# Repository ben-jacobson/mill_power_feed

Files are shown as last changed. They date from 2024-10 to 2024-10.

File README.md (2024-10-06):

# mill_power_feed
Motor control code for milling machine power feed unit. Uses Platform IO with the Arduino library

Requirements:
- Use Platform IO under visual studio code
- If PIO doesn't pick this up from the .ini file, set this up as an Arudino project with the ATMega328P as the target
- If PIO doesn't pick this up from the .ini file, install the library - AccelStepper
- Compile and build in Platform IO

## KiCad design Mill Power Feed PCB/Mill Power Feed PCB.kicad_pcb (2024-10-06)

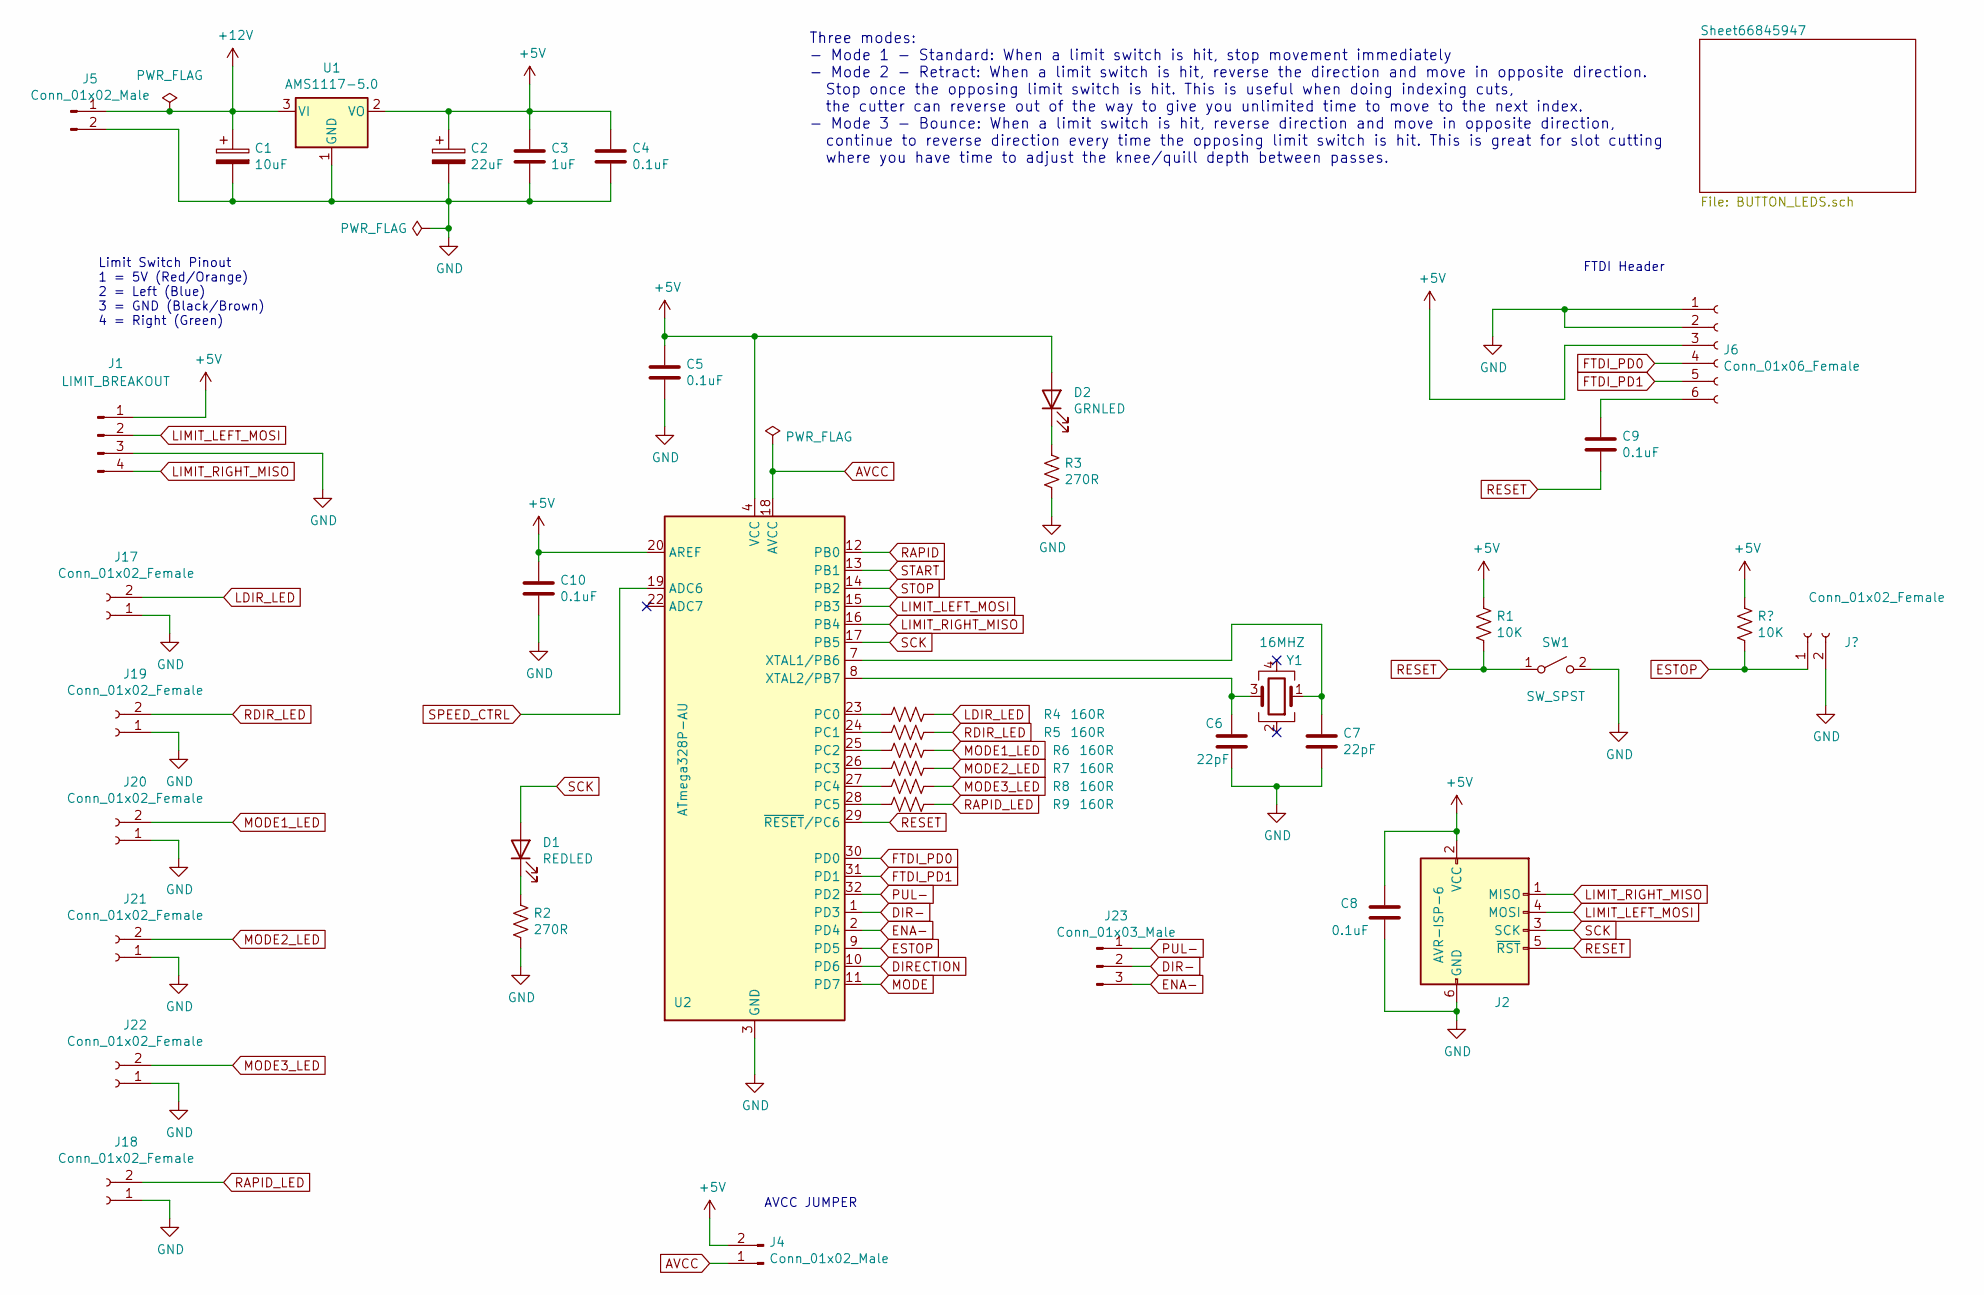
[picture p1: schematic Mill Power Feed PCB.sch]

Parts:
C1: 10uF; C_Elec_4x5.4; LCSC C134721
C2: 22uF; CP_EIA-3528-21_Kemet-B; LCSC C8020
C3: 1uF; C_0603_1608Metric; LCSC C28323
C4, C5, C8, C9, C10: 0.1uF; C_0603_1608Metric; LCSC C14663
C6, C7: 22pF; C_0603_1608Metric; LCSC C388039
D1: REDLED; LED_0603_1608Metric; LCSC C2286
D2: GRNLED; LED_0603_1608Metric; LCSC C72043
J1: LIMIT_BREAKOUT; JST_XH_B4B-XH-AM_1x04_P2.50mm_Vertical
J2: AVR-ISP-6; PinHeader_2x03_P2.54mm_Vertical
J4: Conn_01x02_Male; PinHeader_1x02_P2.54mm_Vertical
J5: Conn_01x02_Male; PinHeader_1x02_P2.54mm_Horizontal
J6: Conn_01x06_Female; PinSocket_1x06_P2.54mm_Vertical
J17, J18, J19, J20, J21, J22: Conn_01x02_Female; JST_XH_B2B-XH-AM_1x02_P2.50mm_Vertical
J23: Conn_01x03_Male; JST_XH_B3B-XH-AM_1x03_P2.50mm_Vertical
R1: 10K; R_0603_1608Metric; LCSC C25804
R2, R3: 270R; R_0603_1608Metric; LCSC C22966
R4, R5, R6, R7, R8, R9: 160R; R_0603_1608Metric
SW1: SW_SPST; SW_Push_1P1T_NO_6x6mm_H9.5mm; LCSC C620316
U1: AMS1117-5.0; SOT-223-3_TabPin2; LCSC C6187
U2: ATmega328P-AU; TQFP-32_7x7mm_P0.8mm; LCSC C14877
Y1: 16MHZ; Crystal_SMD_3225-4Pin_3.2x2.5mm; LCSC C13738

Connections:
+5V: C2.1, C3.1, C4.1, C5.1, C8.1, C10.1, D2.2 (A), J1.1, J2.2 (VCC), J4.2, J6.3, R1.1, U1.2 (VO), U2.4 (VCC), U2.6 (VCC), U2.20 (AREF); also elsewhere on the board
DIR-: J23.2, U2.1 (PD3)
DIRECTION: U2.10 (PD6); also elsewhere on the board
ENA-: J23.3, U2.2 (PD4)
FTDI_PD0: J6.4, U2.30 (PD0)
FTDI_PD1: J6.5, U2.31 (PD1)
GND: C1.2, C2.2, C3.2, C4.2, C5.2, C6.2, C7.2, C8.2, C10.2, J1.3, J2.6 (GND), J5.2, J6.1, J6.2, J17.1, J18.1, J19.1, J20.1, J21.1, J22.1, R2.2, R3.2, SW1.2 (B), U1.1 (GND), U2.3 (GND), U2.5 (GND), U2.21 (GND); also elsewhere on the board
LDIR_LED: J17.2, R4.1
LIMIT_LEFT_MOSI: J1.2, J2.4 (MOSI), U2.15 (PB3)
LIMIT_RIGHT_MISO: J1.4, J2.1 (MISO), U2.16 (PB4)
MODE: U2.11 (PD7); also elsewhere on the board
MODE1_LED: J20.2, R6.1
MODE2_LED: J21.2, R7.1
MODE3_LED: J22.2, R8.1
unnamed: C6.1, U2.8 (XTAL2/PB7), Y1.3
unnamed: C7.1, U2.7 (XTAL1/PB6), Y1.1
unnamed: C9.1, J6.6
unnamed: D1.1 (K), R2.1
unnamed: D2.1 (K), R3.1
unnamed: R4.2, U2.23 (PC0)
unnamed: R5.2, U2.24 (PC1)
unnamed: R6.2, U2.25 (PC2)
unnamed: R7.2, U2.26 (PC3)
unnamed: R8.2, U2.27 (PC4)
unnamed: R9.2, U2.28 (PC5)
PUL-: J23.1, U2.32 (PD2)
RAPID: U2.12 (PB0); also elsewhere on the board
RAPID_LED: J18.2, R9.1
RDIR_LED: J19.2, R5.1
RESET: C9.2, J2.5 (~RST), R1.2, SW1.1 (A), U2.29 (~RESET~/PC6)
SCK: D1.2 (A), J2.3 (SCK), U2.17 (PB5)
SPEED_CTRL: U2.19 (ADC6); also elsewhere on the board
START: U2.13 (PB1); also elsewhere on the board
STOP: U2.14 (PB2); also elsewhere on the board

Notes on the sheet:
AVCC JUMPER
FTDI Header
Three modes: - Mode 1 - Standard: When a limit switch is hit, stop movement immediately - Mode 2 - Retract: When a limit switch is hit, reverse the direction and move in opposite direction. Stop once the opposing limit switch is hit. This is useful when doing indexing cuts, the cutter can reverse o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
Limit Switch Pinout 1 = 5V (Red/Orange) 2 = Left (Blue) 3 = GND (Black/Brown) 4 = Right (Green)

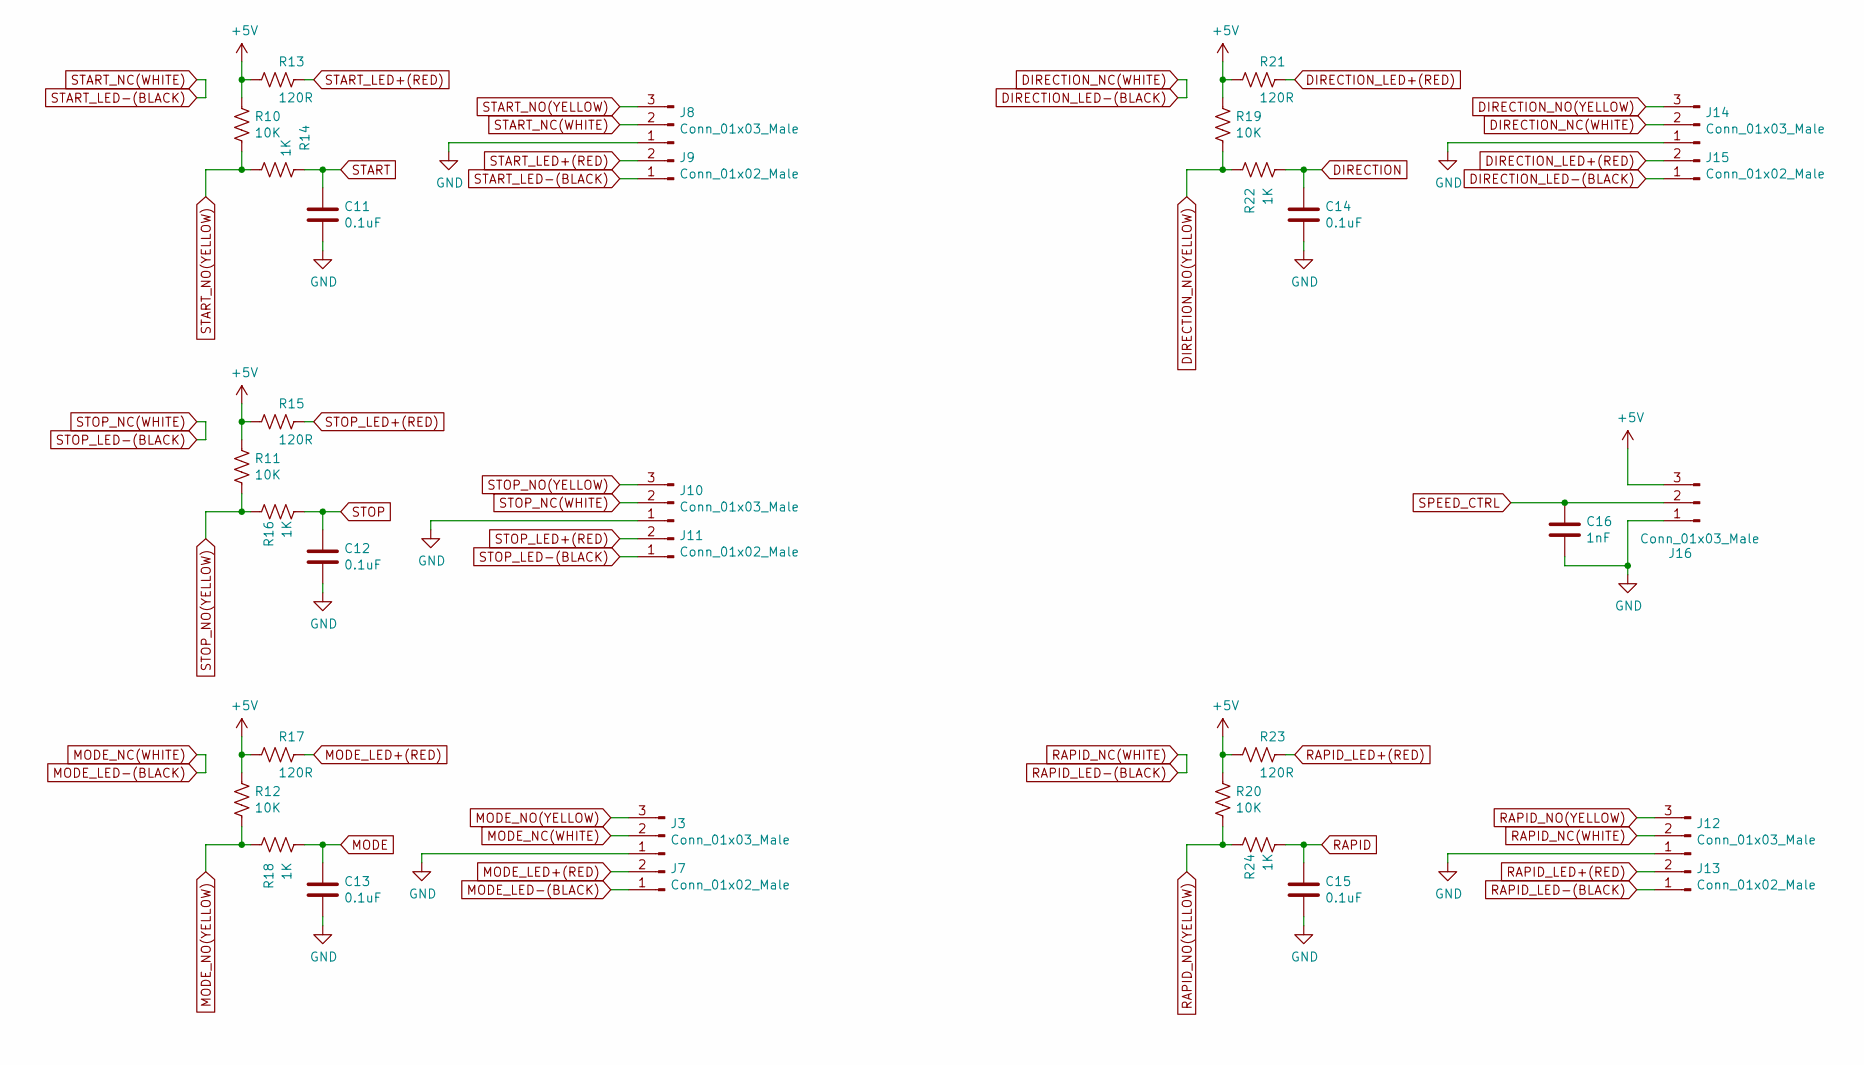
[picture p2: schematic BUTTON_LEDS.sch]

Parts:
C11, C12, C13, C14, C15: 0.1uF; C_0603_1608Metric
C16: 1nF; C_0603_1608Metric
J3, J8, J10, J12, J14, J16: Conn_01x03_Male; JST_XH_B3B-XH-AM_1x03_P2.50mm_Vertical
J7, J9, J11, J13, J15: Conn_01x02_Male; JST_XH_B2B-XH-AM_1x02_P2.50mm_Vertical
R10, R11, R12, R19, R20: 10K; R_0603_1608Metric
R13, R15, R17, R21, R23: 120R; R_0603_1608Metric
R14, R16, R18, R22, R24: 1K; R_0603_1608Metric

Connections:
+5V: J16.3, R10.1, R11.1, R12.1, R13.2, R15.2, R17.2, R19.1, R20.1, R21.2, R23.2; also elsewhere on the board
DIRECTION: C14.1, R22.2; also elsewhere on the board
DIRECTION_LED+(RED): J15.2, R21.1
DIRECTION_LED-(BLACK): J14.2, J15.1
DIRECTION_NO(YELLOW): J14.3, R19.2, R22.1
GND: C11.2, C12.2, C13.2, C14.2, C15.2, C16.2, J3.1, J8.1, J10.1, J12.1, J14.1, J16.1; also elsewhere on the board
MODE: C13.1, R18.2; also elsewhere on the board
MODE_LED+(RED): J7.2, R17.1
MODE_LED-(BLACK): J3.2, J7.1
MODE_NO(YELLOW): J3.3, R12.2, R18.1
RAPID: C15.1, R24.2; also elsewhere on the board
RAPID_LED+(RED): J13.2, R23.1
RAPID_LED-(BLACK): J12.2, J13.1
RAPID_NO(YELLOW): J12.3, R20.2, R24.1
SPEED_CTRL: C16.1, J16.2; also elsewhere on the board
START: C11.1, R14.2; also elsewhere on the board
START_LED+(RED): J9.2, R13.1
START_LED-(BLACK): J8.2, J9.1
START_NO(YELLOW): J8.3, R10.2, R14.1
STOP: C12.1, R16.2; also elsewhere on the board
STOP_LED+(RED): J11.2, R15.1
STOP_LED-(BLACK): J10.2, J11.1
STOP_NO(YELLOW): J10.3, R11.2, R16.1

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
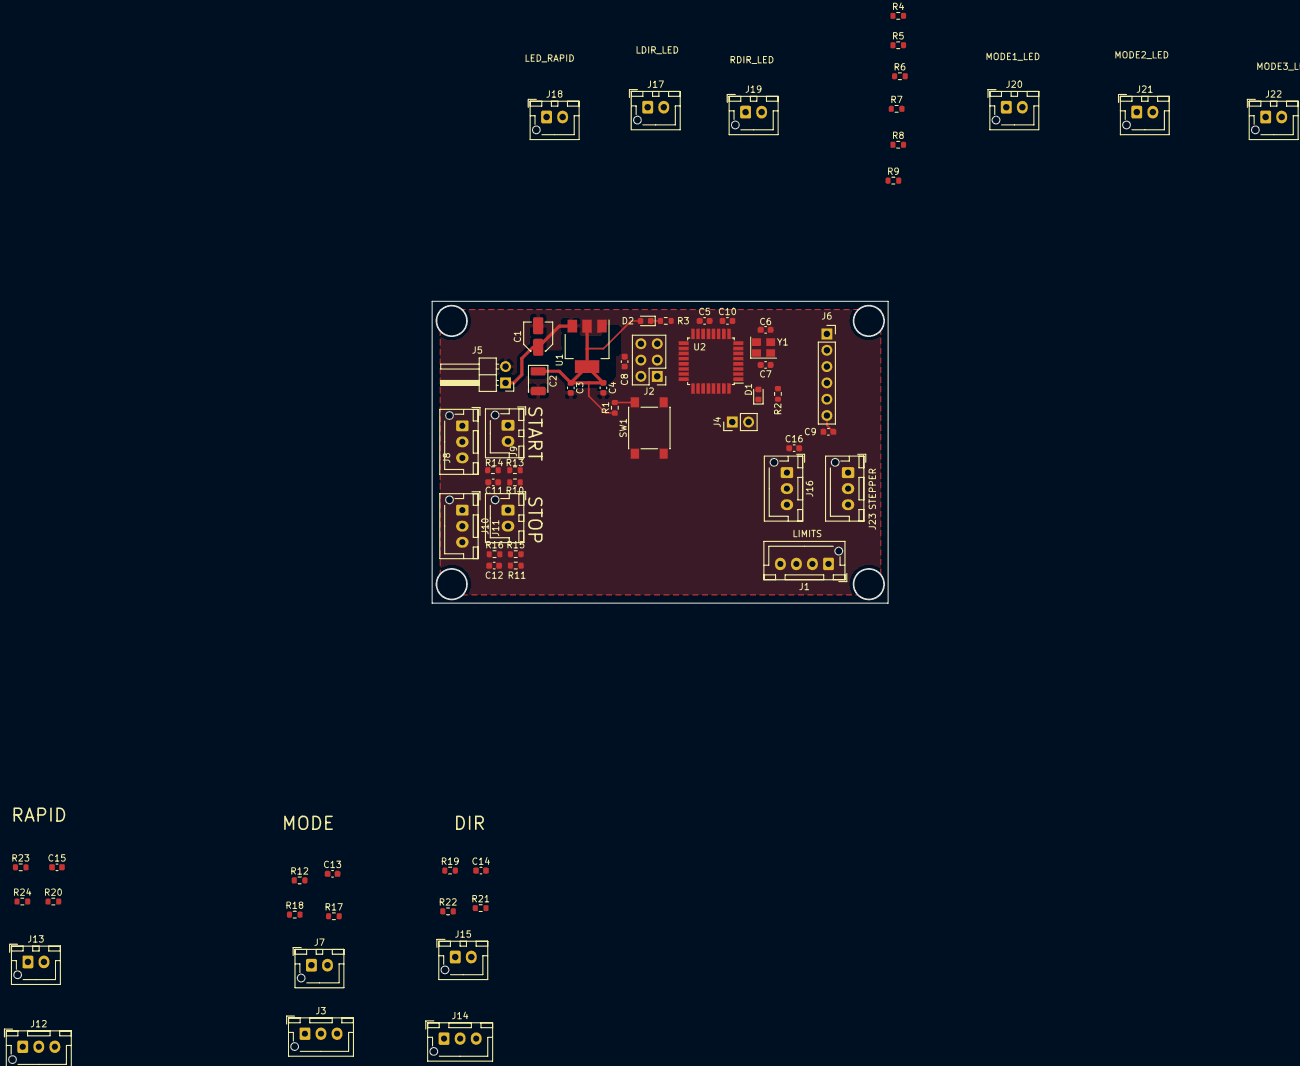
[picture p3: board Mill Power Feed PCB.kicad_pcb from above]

Board: 2 copper layers, 71.0 x 47.0 mm, 69 parts (0 on the bottom side), 51 nets.

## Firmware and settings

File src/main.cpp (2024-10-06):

#include <Arduino.h>
#include <AccelStepper.h>

// Debug flag, comment out when deploying stable coad. Will disable all serial output and speeds up execution
//#define DEBUG 

// Button pins - order on PCB is Stop, Start, Rapid, Mode, Direction
#define DIRECTION_BUTTON_PIN 6   // Pin for direction button
#define MODE_BUTTON_PIN 7        // Pin for mode select button
#define RAPID_BUTTON_PIN 8         // Pin for rapid mode 
#define START_BUTTON_PIN 9       // Pin for start button
#define STOP_BUTTON_PIN 10       // Pin for stop button
#define LIMIT_LEFT_PIN 12       // Limit switch left
#define LIMIT_RIGHT_PIN 11       // Limit switch right


// eSTOP - Important - the NC side of the switch is used to disconnect power. However since the PSUs have some charge left in the caps, 
// it doesn't halt exection or stop motors right away. The solution is to connect a Digital pin to the the NO side of the eStop. trigger an interrupt to halt the motor
#define ESTOP_BUTTON_PIN 5 // note that pin 5 doesnt support interupt, need to re-arrange in hardware and retry implementation. 

// Debouncing
bool direction_button_debounce = false; 
bool mode_button_debounce = false; 
bool rapid_button_debounce = false; 
bool start_button_debounce = false; 
bool stop_button_debounce = false; 

// LEDs                                                                                              
#define LED_RIGHT_DIRECTION A1
#define LED_LEFT_DIRECTION A2
#define LED_STANDARD_MODE A3    
#define LED_RETRACT_MODE A4           
#define LED_BOUNCE_MODE A5    
#define LED_RAPID A0 

// directions
#define LEFT LOW
#define RIGHT HIGH
byte move_direction; 

// modes
#define MODE_STANDARD 0      
#define MODE_RETRACT 1            
#define MODE_BOUNCE 2  
byte mode;
bool retracting = false; 
bool rapid_movement = false; 

// Stepper driver
#define STEPPER_PULSE_PIN 2
#define STEPPER_DIR_PIN 3
#define STEPPER_ENABLE_PIN 4

AccelStepper stepper(AccelStepper::DRIVER, STEPPER_PULSE_PIN, STEPPER_DIR_PIN);
bool motor_running;

// Speed settings
#define SPEED_POT A6              // Analog pin for speed potentiometer
#define POT_HYSTERSIS 5           // a predefined value to prevent continuous reading of the pot due to spurious noise, will ignore the noise and only read a new value if the pot moves by x or more increments.
#define CYCLE_SKIP_SPEED_CHECK 1000
int cycle_check = 0;  // used so that the speed isn't being read every cycle, this prevents the user from updating the speed so frequently that the stepper wigs out.

// Stepper speeds
#define STEPPER_MIN_SPEED 2 
#define STEPPER_MAX_SPEED 900
#define STEPPER_MAX_ACCEL 1000
#define STEPPER_RAPID 2000

int speed_pot_reading, last_speed_pot_reading; 

void clear_mode_status_leds(void) {
    digitalWrite(LED_STANDARD_MODE, LOW);
    digitalWrite(LED_RETRACT_MODE, LOW);
    digitalWrite(LED_BOUNCE_MODE, LOW);
}

void stop_motor_emergency(void) {
    stepper.disableOutputs(); // doing this before stop will mean the system stops without decelleration
    stepper.stop(); 
    motor_running = false;  
}

void stop_motor(void) {
    if (motor_running) {    
        stepper.stop(); 
        motor_running = false;  
    }
}

void setup() {
    #ifdef DEBUG
        // Initialize Serial communication
        Serial.begin(9600);
    #endif
  
    // Set button pins as inputs
    pinMode(DIRECTION_BUTTON_PIN, INPUT);
    pinMode(MODE_BUTTON_PIN, INPUT);
    pinMode(RAPID_BUTTON_PIN, INPUT);  
    pinMode(START_BUTTON_PIN, INPUT);
    pinMode(STOP_BUTTON_PIN, INPUT);
    pinMode(LIMIT_LEFT_PIN, INPUT);
    pinMode(LIMIT_RIGHT_PIN, INPUT);    
  
    // set analog speed input
    pinMode(SPEED_POT, INPUT);
  
    // set LED outputs
    pinMode(LED_RAPID, OUTPUT);
    pinMode(LED_LEFT_DIRECTION, OUTPUT);
    pinMode(LED_RIGHT_DIRECTION, OUTPUT);
    pinMode(LED_STANDARD_MODE, OUTPUT);
    pinMode(LED_RETRACT_MODE, OUTPUT);
    pinMode(LED_BOUNCE_MODE, OUTPUT);
  
    // init the mode
    mode = MODE_STANDARD;
    clear_mode_status_leds();
    digitalWrite(LED_STANDARD_MODE, HIGH);
  
    // init the direction
    move_direction = LEFT; // start moving left
    digitalWrite(LED_LEFT_DIRECTION, HIGH);  
    digitalWrite(LED_RIGHT_DIRECTION, LOW);     

    // set up stepper motor
    pinMode (STEPPER_PULSE_PIN, OUTPUT);
    pinMode (STEPPER_DIR_PIN, OUTPUT);
    pinMode (STEPPER_ENABLE_PIN, OUTPUT);
    stepper.setEnablePin(STEPPER_ENABLE_PIN);
    stepper.setMaxSpeed(STEPPER_MIN_SPEED);
    stepper.setAcceleration(STEPPER_MAX_ACCEL);

    // for safety
    stop_motor();

    // set up the interrupt for emergency stop
    //attachInterrupt(digitalPinToInterrupt(ESTOP_BUTTON_PIN), stop_motor_emergency, LOW); // have not yet implemented in hardware, will disable for now
    
    #ifdef DEBUG
        Serial.println("Program start");
    #endif
}


void loop() {

    cycle_check++; 

    if (cycle_check > CYCLE_SKIP_SPEED_CHECK && rapid_movement == false) { // only allow speed change occasionally, also ignore if the rapid button is being pressed.
        speed_pot_reading = map(analogRead(SPEED_POT), 1024, 0, STEPPER_MIN_SPEED, STEPPER_MAX_SPEED); // if wired correctly the value of the pot will be zero ohms read at the left most position. Simply flip the first 1024, and 0 to read 0, 1024.

        if (speed_pot_reading < last_speed_pot_reading - POT_HYSTERSIS || speed_pot_reading > last_speed_pot_reading + POT_HYSTERSIS) {
            #ifdef DEBUG 
                Serial.print(F("Changing speed to: "));
                Serial.println(speed_pot_reading);
            #endif
            
            last_speed_pot_reading = speed_pot_reading;
            stepper.setMaxSpeed(last_speed_pot_reading);
        }
        cycle_check = 0;
    }

    if (digitalRead(LIMIT_LEFT_PIN) == LOW) {
        #ifdef DEBUG 
            if (move_direction == LEFT && motor_running == true)
                Serial.println(F("Left Limit Switch Hit"));
        #endif

        if (move_direction == LEFT && motor_running == true) {

            if (rapid_movement == true) {
                // very easy to shoot past limit switches if you rapid into a limit switch
                stop_motor_emergency();
            }

            if (mode == MODE_STANDARD) {
                stop_motor();
            }
            if (mode == MODE_RETRACT) {
                if (retracting == false) {
                    retracting = true;
                    move_direction = RIGHT;                         
                }
                else {
                    retracting = false;   
                    stop_motor();       
                    move_direction = RIGHT;    // reset direction back to original
                }                
            }
            if (mode == MODE_BOUNCE) {
                move_direction = RIGHT;      
            }
        }
    }

    if (digitalRead(LIMIT_RIGHT_PIN) == LOW) {
        #ifdef DEBUG 
            if (move_direction == RIGHT && motor_running == true)
                Serial.println(F("Right Limit Switch Hit"));
        #endif      
   
        if (move_direction == RIGHT && motor_running == true) {
            if (rapid_movement == true) {
                // very easy to shoot past limit switches if you rapid into a limit switch
                stop_motor_emergency();
            }

            if (mode == MODE_STANDARD) {
                stop_motor();                   
            }
            if (mode == MODE_RETRACT) {
                if (retracting == false) {
                    retracting = true;
                    move_direction = LEFT;                         
                }
                else {
                    retracting = false;   
                    stop_motor();
                    move_direction = LEFT;    // reset direction back to original and repeat.
                }  
            }
            if (mode == MODE_BOUNCE) {
                move_direction = LEFT;      
            }
        }
    }    
 
    if (digitalRead(DIRECTION_BUTTON_PIN) == LOW && direction_button_debounce == false) { 

        if (!motor_running) {
            #ifdef DEBUG 
                Serial.print(F("Direction Button Pressed, changing direction to: "));
            #endif
                
            switch (move_direction) {
                case LEFT:
                    #ifdef DEBUG 
                        Serial.println(F("RIGHT")); 
                    #endif
                    move_direction = RIGHT;
                    break;
                case RIGHT :
                    #ifdef DEBUG
                        Serial.println(F("LEFT")); 
                    #endif
                    move_direction = LEFT;                    
                    break;
                default:
                    #ifdef DEBUG 
                        Serial.println(F("Undefined")); 
                    #endif
                    break;
            }
        }
        else {
            #ifdef DEBUG 
                Serial.println(F("Direction Button Pressed while motor running, ignoring command."));
            #endif
        }
        direction_button_debounce = true;

    }  
    if (digitalRead(DIRECTION_BUTTON_PIN) == HIGH) {         
        direction_button_debounce = false;
    }  


    if (move_direction == LEFT) {
        digitalWrite(LED_LEFT_DIRECTION, HIGH);
        digitalWrite(LED_RIGHT_DIRECTION, LOW);
    }
    if (move_direction == RIGHT) {
        digitalWrite(LED_LEFT_DIRECTION, LOW);
        digitalWrite(LED_RIGHT_DIRECTION, HIGH);
    }

    if (digitalRead(MODE_BUTTON_PIN) == LOW && mode_button_debounce == false) { 
        #ifdef DEBUG 
            Serial.print(F("Mode Button Pressed, current mode is: ")); 
        #endif

        mode = (mode + 1) % 3;
        clear_mode_status_leds();

        switch (mode) {
            case MODE_STANDARD:
                #ifdef DEBUG 
                    Serial.println(F("Standard")); 
                #endif
                digitalWrite(LED_STANDARD_MODE, HIGH);
                break;
            case MODE_RETRACT:
                #ifdef DEBUG
                    Serial.println(F("Retract")); 
                #endif
                digitalWrite(LED_RETRACT_MODE, HIGH);
                break;
            case MODE_BOUNCE:
                #ifdef DEBUG 
                    Serial.println(F("Bounce")); 
                #endif
                digitalWrite(LED_BOUNCE_MODE, HIGH);
                break;
            default:
                #ifdef DEBUG 
                    Serial.println(F("Undefined")); 
                #endif
                break;
        }           
        mode_button_debounce = true;
    }  
    if (digitalRead(MODE_BUTTON_PIN) == HIGH) {         
        mode_button_debounce = false;
    }  

    if (digitalRead(RAPID_BUTTON_PIN) == LOW && rapid_button_debounce == false) { 
        #ifdef DEBUG 
            Serial.println(F("Rapid Button Pressed"));
        #endif
        stepper.setMaxSpeed(STEPPER_RAPID);
        rapid_button_debounce = true;
        rapid_movement = true; 
    }  
    if (digitalRead(RAPID_BUTTON_PIN) == HIGH) {     
        stepper.setMaxSpeed(last_speed_pot_reading);    
        rapid_button_debounce = false;
        rapid_movement = false;
    }      

    if (digitalRead(START_BUTTON_PIN) == LOW && start_button_debounce == false) {
        #ifdef DEBUG  
            Serial.println(F("Start Button Pressed"));
        #endif
        stepper.enableOutputs();    
       
        motor_running = true; 
        start_button_debounce = true;
    }  
    if (digitalRead(START_BUTTON_PIN) == HIGH) {      
        start_button_debounce = false;
    }  

    if (digitalRead(STOP_BUTTON_PIN) == LOW && stop_button_debounce == false) { 
        #ifdef DEBUG 
            Serial.println(F("Stop Button Pressed"));
        #endif
        stop_motor();
        stop_button_debounce = true;
    }  
    if (digitalRead(STOP_BUTTON_PIN) == HIGH) {   
        stop_button_debounce = false;
    }

    /*if (mode == MODE_BOUNCE || mode == MODE_RETRACT)       // stop the stepper from continuing past limit switch     
        stepper.setAcceleration(STEPPER_MAX_ACCEL * 2);     
    else 
        stepper.setAcceleration(STEPPER_MAX_ACCEL);
    */ // found this to be unnecessary with proximity switches as the sensor detects the limit a few mm away, likely to be necessary if using switch based limits

    if (move_direction == LEFT && motor_running) {
        stepper.moveTo(1000000);          
    }   
    else if (move_direction == RIGHT && motor_running) {
        stepper.moveTo(-1000000);  
    }    

    stepper.run();     
}

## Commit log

2024-10-06 Tidied up stop code, added an extra pin for eStop and attached an interrupt, will enable it when we add in hardware
2024-10-06 Tweaked acceleration to the kinematics of the machine, however am having trouble now the stop function within the library seems to ignore deceleration, may need to refactor and use a new library...
2024-10-06 fixed issue where motor stopping would stop without decelleration, also put in new safety feature to prevent rapiding into limit switches.
    [main.cpp]
2024-10-06 Added kicad schematics
    Board layout is incomplete. Decision was made to switch from JST crimp connectors to phoenix connectors which hasn't happened yet.
    [BUTTON_LEDS.sch, Mill Power Feed PCB.kicad_pcb, Mill Power Feed PCB.sch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]
